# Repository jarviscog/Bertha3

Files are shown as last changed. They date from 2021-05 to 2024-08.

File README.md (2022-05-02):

# Bertha3

Bertha3 is a design of a split-flap display.

## Parts

Parts designed in Solidworks, and printed using the Ender3

## Parts used

[Stepper motor](https://www.adafruit.com/product/858)

## Code structure

The split flap is made up of a 2D array of split flaps called ```Bits```. The ```BitArray``` class controls all of the bits from 
one place. This is where you would print anything to the screen, or do any animations.
Create a new ```BitArray``` object, and call the functions inside to change what is displayed on the screen.

```display_layered_strings()``` is the highest level function for printing to the screen, printing an array of strings in any formatting you would like (see the docstring for more info)

Many different functions have been created to make writing to the screen as easy as possible.

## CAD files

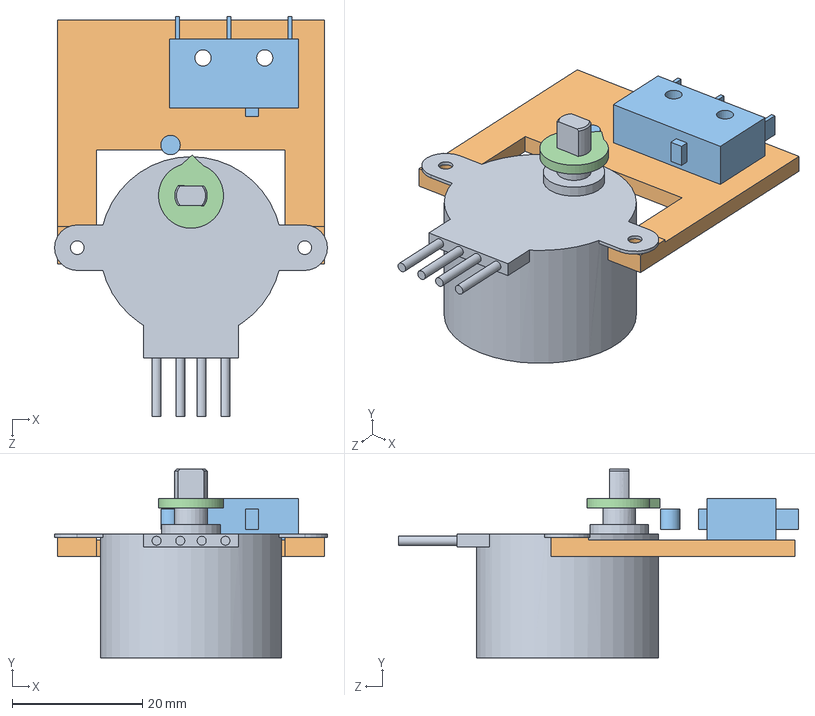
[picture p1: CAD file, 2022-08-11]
CAD Files/assemblies/position_encoder.SLDASM
42.0 x 29.0 x 61.6 mm
Motor
encoder_bracket
microswitch
rotating_thing_encoder

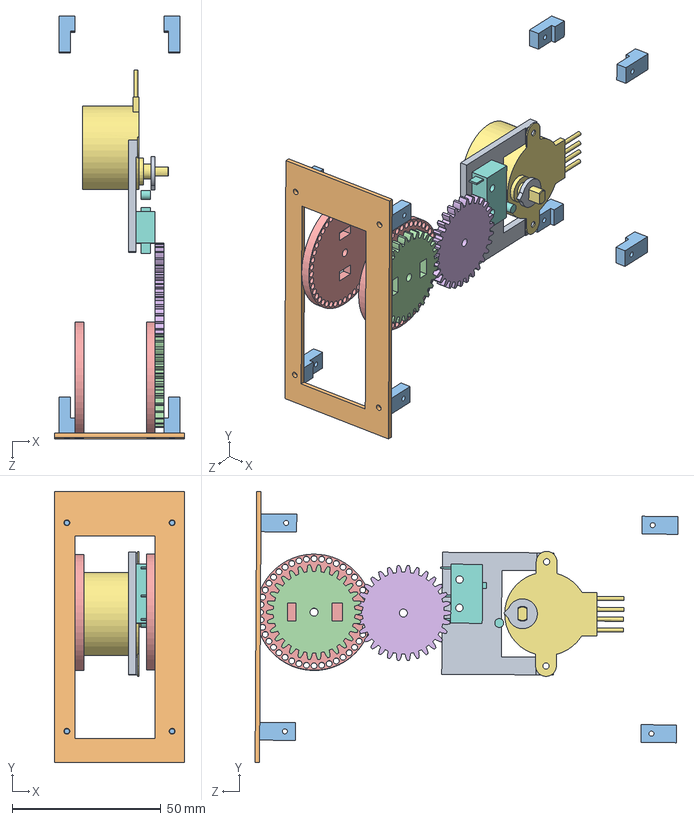
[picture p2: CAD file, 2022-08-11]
CAD Files/assemblies/mybit.SLDASM
43.7 x 91.0 x 142.0 mm
frontv2
fasteners x 8
barrel_gear
BarrelSide x 2
gear2
Motor
encoder_bracket
microswitch
rotating_thing_encoder

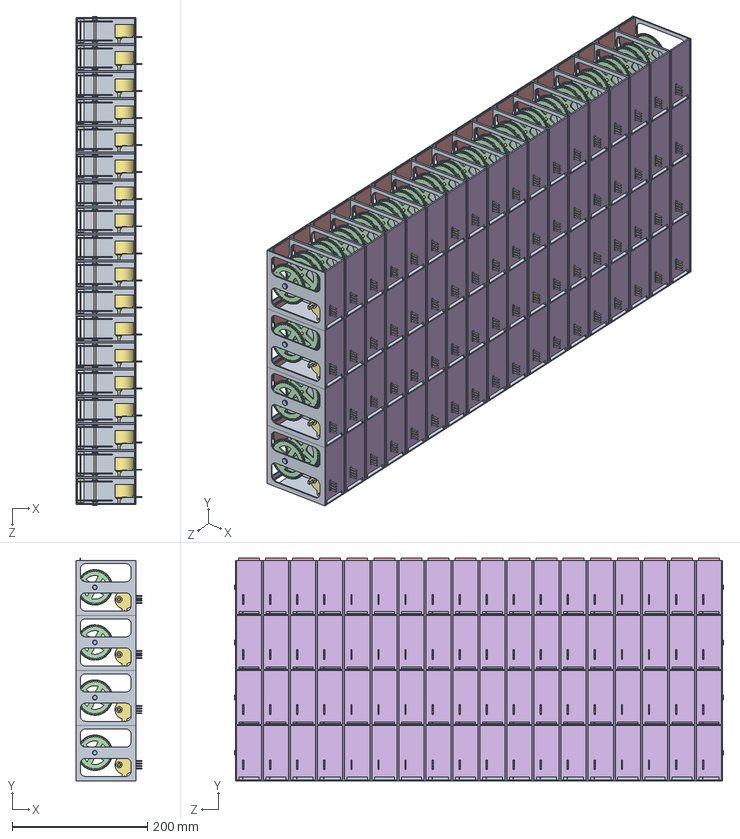
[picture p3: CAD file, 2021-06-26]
Parts/Screen.SLDASM
97.8 x 329.0 x 723.0 mm
Metal Rod x 72
EndCap x 144
SinisterGear x 144
Flap x 72
RearBox x 72
Motor x 72

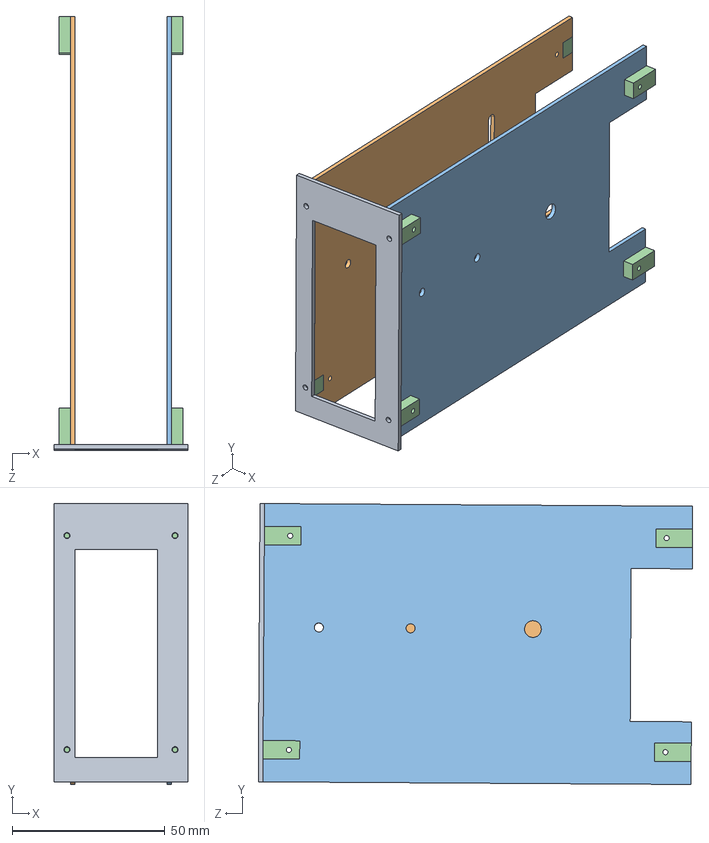
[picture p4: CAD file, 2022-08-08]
CAD Files/assemblies/mybit_frame.SLDASM
43.7 x 91.9 x 142.1 mm
Left
Right
frontv2
fasteners x 8

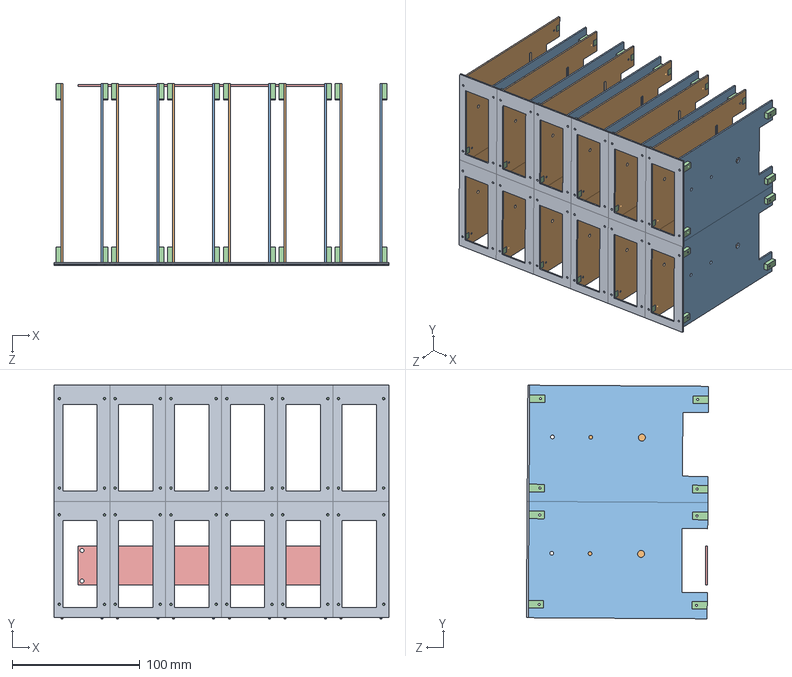
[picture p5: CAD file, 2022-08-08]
CAD Files/assemblies/simple_bit_assembly.SLDASM
262.2 x 182.9 x 142.6 mm
Left x 12
Right x 12
frontv2 x 12
fasteners x 96
motor_driver_pcb

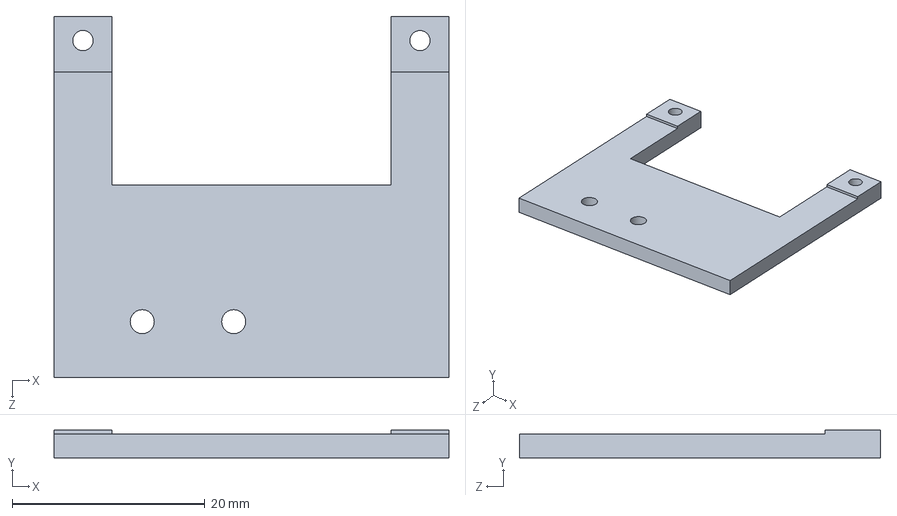
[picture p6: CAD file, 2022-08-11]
CAD Files/parts/encoder_bracket.SLDPRT
41.0 x 2.90 x 37.5 mm

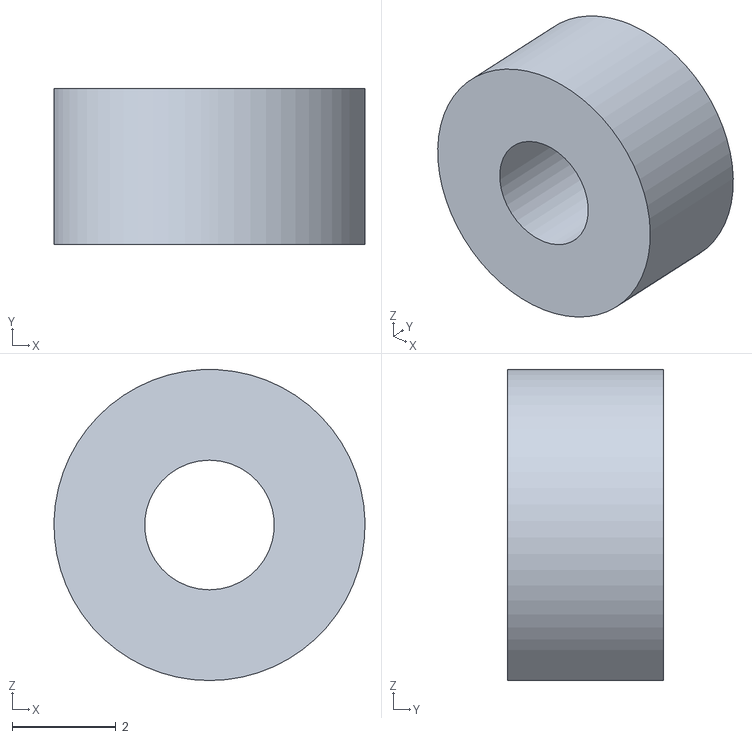
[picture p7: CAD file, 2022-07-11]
CAD Files/STL Files/spacer.STL
6.00 x 3.00 x 6.00

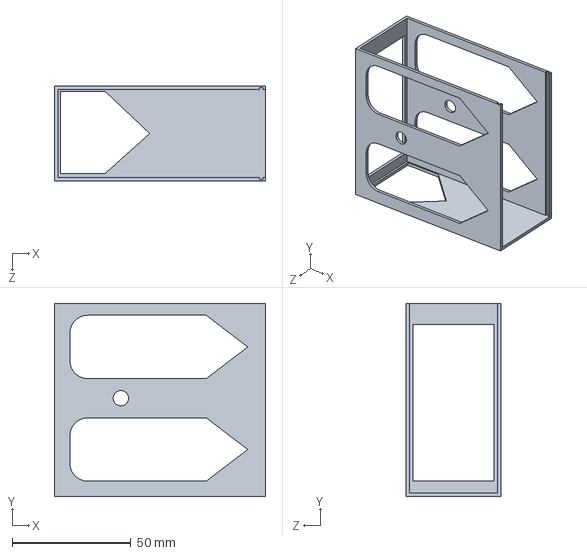
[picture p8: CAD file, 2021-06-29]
Parts/Box.SLDPRT
89.0 x 81.5 x 40.0 mm

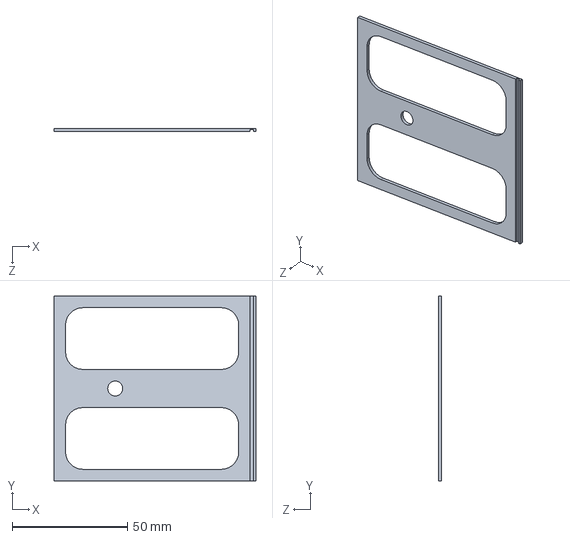
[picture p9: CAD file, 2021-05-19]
Parts/Box/LeftSideBox.SLDPRT
87.5 x 80.0 x 1.50 mm

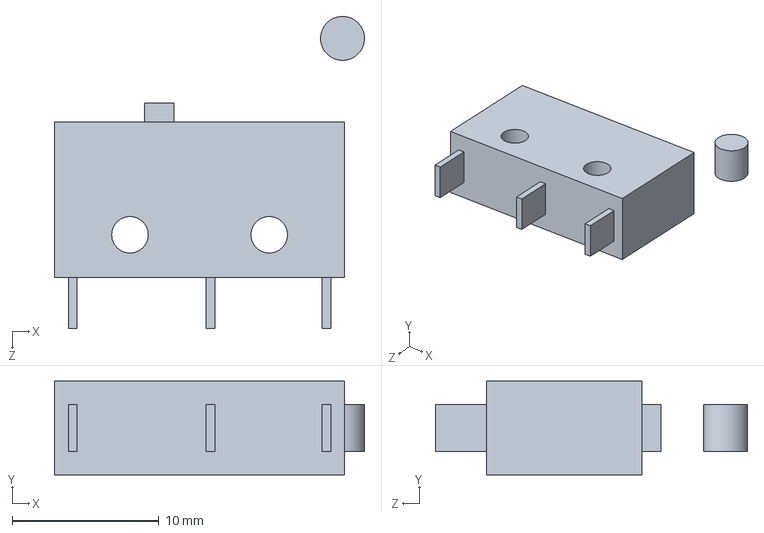
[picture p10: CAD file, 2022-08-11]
CAD Files/parts/microswitch.SLDPRT
21.1 x 6.40 x 21.3 mm

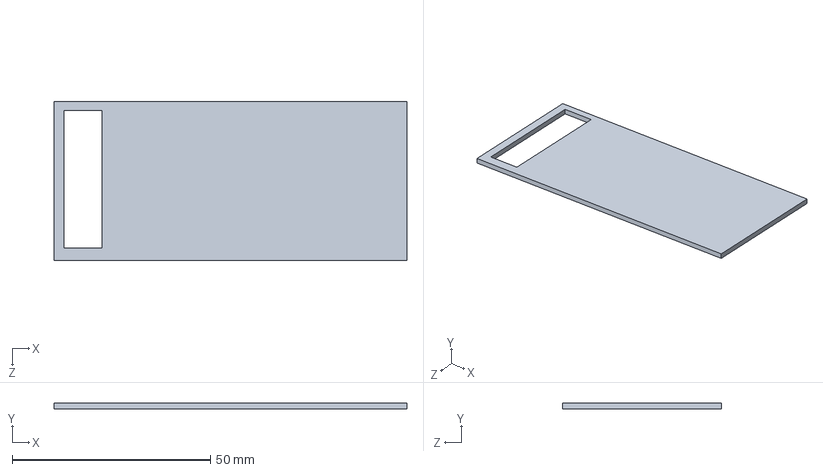
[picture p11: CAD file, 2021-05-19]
Parts/Box/BottomBox.SLDPRT
89.0 x 1.50 x 40.0 mm

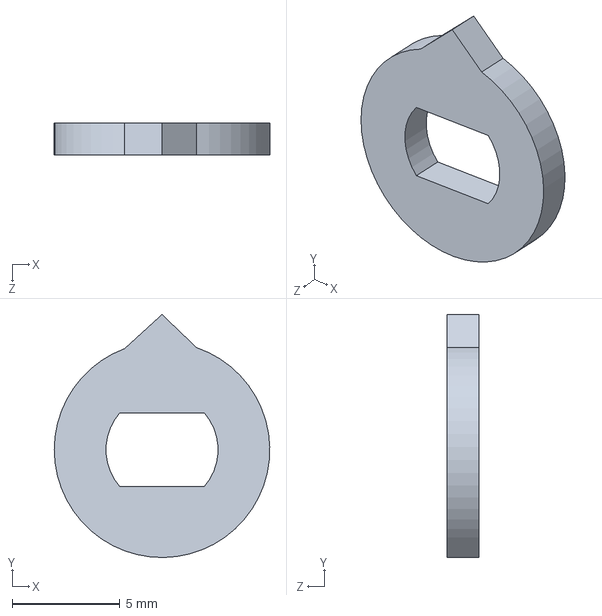
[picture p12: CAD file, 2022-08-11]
CAD Files/parts/rotating_thing_encoder.SLDPRT
10.00 x 11.3 x 1.50 mm

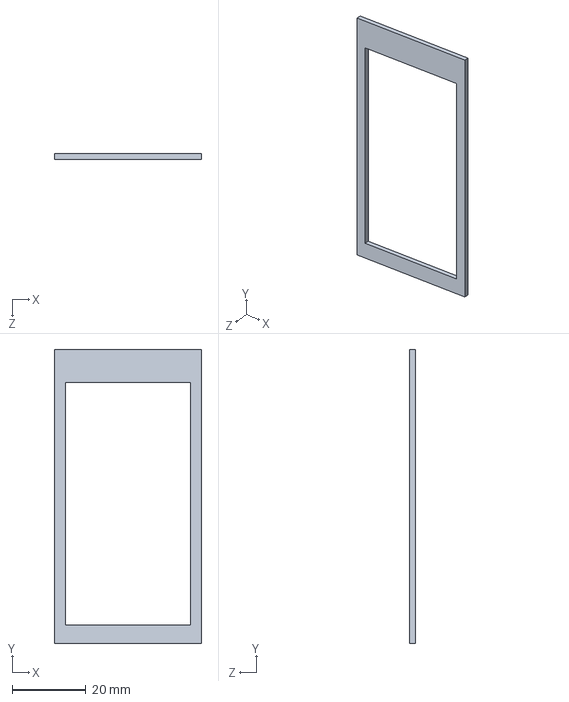
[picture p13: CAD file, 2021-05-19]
Parts/Box/FrontBox.SLDPRT
40.0 x 80.0 x 1.50 mm

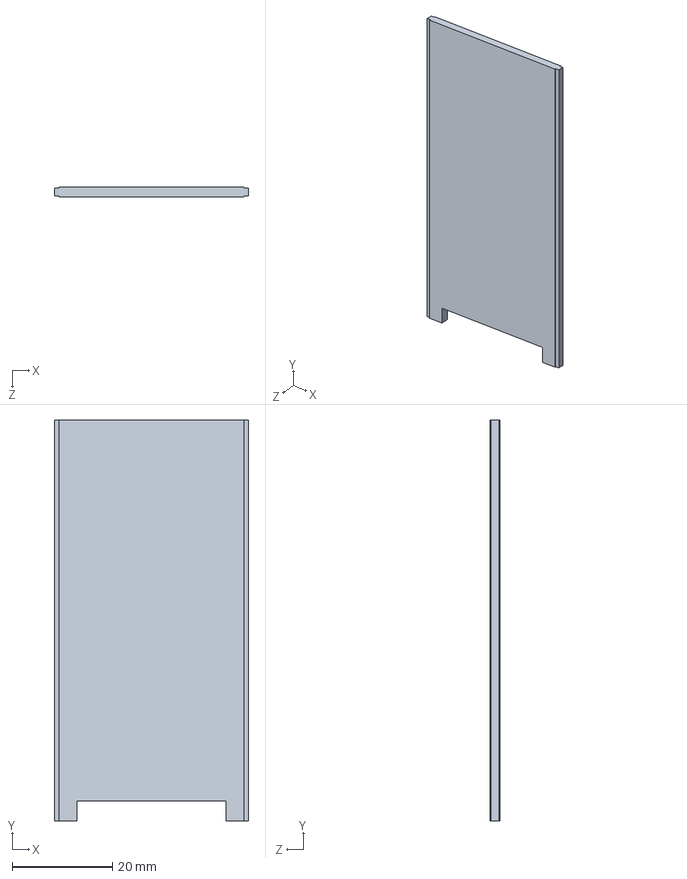
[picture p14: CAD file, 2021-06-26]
Parts/RearBox.SLDPRT
38.8 x 80.0 x 2.00 mm

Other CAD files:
CAD Files/parts/frontv2.SLDPRT
Parts/EndCap.SLDPRT
CAD Files/parts/fasteners.SLDPRT
Parts/SinisterGear.SLDPRT
CAD Files/STL Files/InnerBarrelStandoff.STL
CAD Files/STL Files/encoder_bracket.STL
CAD Files/STL Files/motor_standoff.STL
CAD Files/STL Files/rotating_thing_encoder.STL
CAD Files/drawings/Laser.SLDDRW
CAD Files/drawings/for_laser_cutting.SLDDRW
CAD Files/drawings/multipart2.SLDDRW
CAD Files/drawings/some_more_laser_cutting.SLDDRW
CAD Files/parts/Axel.SLDPRT
CAD Files/parts/BarrelSide.SLDPRT
CAD Files/parts/HallSensor.SLDPRT
CAD Files/parts/HallSensorStandoff.SLDPRT
CAD Files/parts/InnerBarrelStandoff.SLDPRT
CAD Files/parts/Left.SLDPRT
CAD Files/parts/Motor.SLDPRT
CAD Files/parts/Right.SLDPRT
CAD Files/parts/Standoff.SLDPRT
CAD Files/parts/backplate.SLDPRT
CAD Files/parts/barrel_gear.SLDPRT
CAD Files/parts/driving_gear.SLDPRT
CAD Files/parts/flapv2.SLDPRT
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

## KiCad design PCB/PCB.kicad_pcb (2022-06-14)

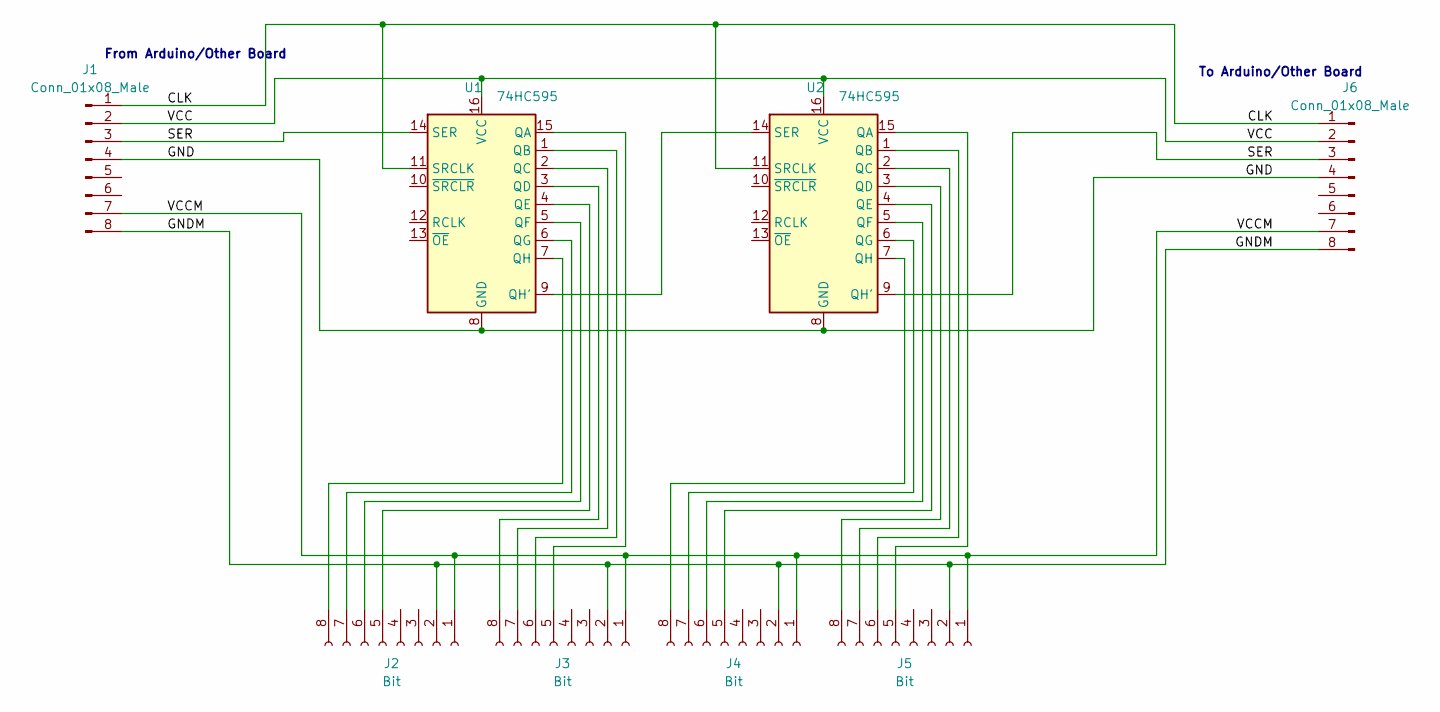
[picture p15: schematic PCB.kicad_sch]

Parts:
J1, J6: Conn_01x08_Male; JST_EH_B8B-EH-A_1x08_P2.50mm_Vertical
J2, J3, J4, J5: Bit; JST_EH_B8B-EH-A_1x08_P2.50mm_Vertical
U1, U2: 74HC595; DIP-16_W7.62mm_SMDSocket_SmallPads

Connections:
/CLK: J1.1, J6.1, U1.11 (SRCLK), U2.11 (SRCLK)
/GND: J1.4, J6.4, U1.8 (GND), U2.8 (GND)
/GNDM: J1.8, J2.2, J3.2, J4.2, J5.2, J6.8
/SER: J1.3, J6.3, U1.14 (SER), U2.9 (QH')
/VCC: J1.2, J6.2, U1.16 (VCC), U2.16 (VCC)
/VCCM: J1.7, J2.1, J3.1, J4.1, J5.1, J6.7
unnamed: J2.5, U1.4 (QE)
unnamed: J2.6, U1.5 (QF)
unnamed: J2.7, U1.6 (QG)
unnamed: J2.8, U1.7 (QH)
unnamed: J3.5, U1.15 (QA)
unnamed: J3.6, U1.1 (QB)
unnamed: J3.7, U1.2 (QC)
unnamed: J3.8, U1.3 (QD)
unnamed: J4.5, U2.4 (QE)
unnamed: J4.6, U2.5 (QF)
unnamed: J4.7, U2.6 (QG)
unnamed: J4.8, U2.7 (QH)
unnamed: J5.5, U2.15 (QA)
unnamed: J5.6, U2.1 (QB)
unnamed: J5.7, U2.2 (QC)
unnamed: J5.8, U2.3 (QD)
unnamed: U1.9 (QH'), U2.14 (SER)

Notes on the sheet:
From Arduino/Other Board
To Arduino/Other Board

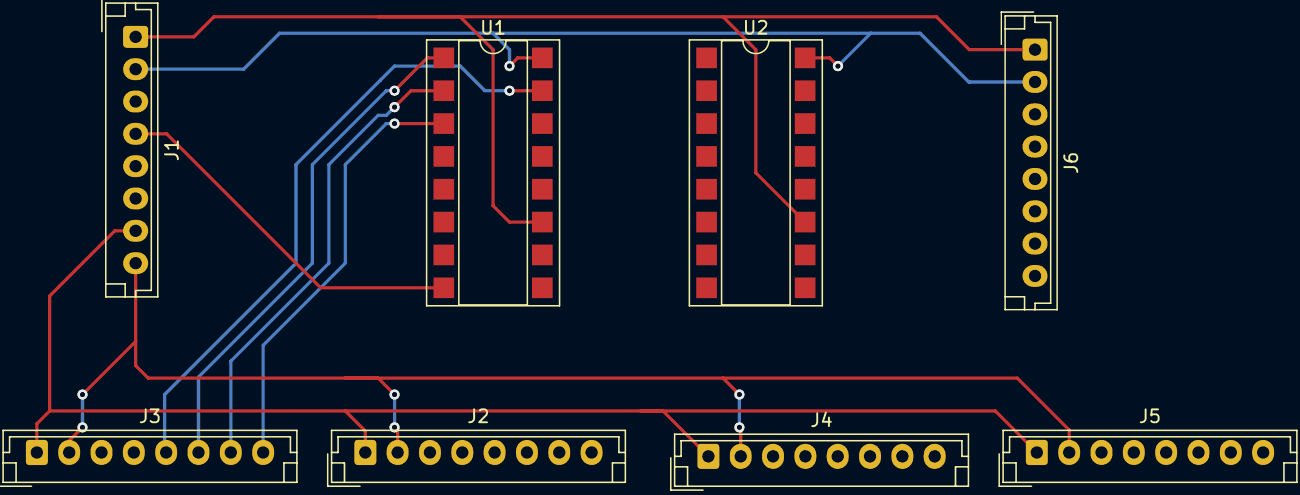
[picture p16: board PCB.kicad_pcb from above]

Board: 2 copper layers, 8 parts (0 on the bottom side), 23 nets.

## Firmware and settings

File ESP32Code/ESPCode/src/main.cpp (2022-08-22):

// /*
//   WiFiAccessPoint.ino creates a WiFi access point and provides a web server on it.

//   Steps:
//   1. Connect to the access point "yourAp"
//   2. Point your web browser to http://192.168.4.1/H to turn the LED on or http://192.168.4.1/L to turn it off
//     OR
//     Run raw TCP "GET /H" and "GET /L" on PuTTY terminal with 192.168.4.1 as IP address and 80 as port

//   Created for arduino-esp32 on 04 July, 2018
//   by Elochukwu Ifediora (fedy0)
// */


// #include <WiFi.h>
// #include <WiFiClient.h>
// #include <WiFiAP.h>

// // Control the builtin led
// #include "Freenove_WS2812_Lib_for_ESP32.h"
// #define LEDS_COUNT  8
// #define LEDS_PIN	48
// #define CHANNEL		0
// Freenove_ESP32_WS2812 rgb_led = Freenove_ESP32_WS2812(LEDS_COUNT, LEDS_PIN, CHANNEL, TYPE_GRB);
// byte m_color[5][3] = { {255, 0, 0}, {0, 255, 0}, {0, 0, 255}, {255, 255, 255}, {0, 0, 0} };

// byte RED[3] = {255,0,0};
// byte GREEN[3] = {0,255,0};
// byte BLUE[3] = {0,0,255};


// // WIFI Cridentials
// const char *ssid = "AeroBoard";
// const char *password = "esp32";

// WiFiServer server(80);

// void set_led(byte color[3]){

//     for (int i = 0; i < LEDS_COUNT; i++) {
// 			rgb_led.setLedColorData(i, color[0], color[1], color[2]);
// 			rgb_led.show();
// 			// delay(2);
// 	}


// }



// void setup() {

//     // Setup LED for debugging
//     rgb_led.begin();
//     rgb_led.setBrightness(100);

//     Serial.begin(115200);
//     Serial.println();
//     Serial.println("Configuring access point...");

//     // You can remove the password parameter if you want the AP to be open.
//     WiFi.softAP(ssid, password);
//     IPAddress myIP = WiFi.softAPIP();
//     Serial.print("AP IP address: ");
//     Serial.println(myIP);
//     server.begin();

//     Serial.println("Server started");
// }

// void loop() {
    
    
//     set_led(RED);
//     // Serial.println("Set color");


//     WiFiClient client = server.available();   // listen for incoming clients
//     if (client) {                             // if you get a client,
//     Serial.println("New Client connected");           // print a message out the serial port
//     String currentLine = "";                // make a String to hold incoming data from the client
//     while (client.connected()) {            // loop while the clWient's connected
//         // set_led(BLUE);
//         if (client.available()) {             // if there's bytes to read from the client,
//         char c = client.read();             // read a byte, then
//         Serial.write(c);                    // print it out the serial monitor
//         if (c == '\n') {                    // if the byte is a newline character

//             // if the current line is blank, you got two newline characters in a row.
//             // that's the end of the client HTTP request, so send a response:
//             if (currentLine.length() == 0) {
//             // HTTP headers always start with a response code (e.g. HTTP/1.1 200 OK)
//             // and a content-type so the client knows what's coming, then a blank line:
//             // client.println("HTTP/1.1 200 OK");
//             // client.println("Content-type:text/html");
//             // client.println();

//             // // the content of the HTTP response follows the header:
//             // client.print("Click <a href=\"/H\">here</a> to turn ON the LED.<br>");
//             // client.print("Click <a href=\"/L\">here</a> to turn OFF the LED.<br>");

//             // The HTTP response ends with another blank line:
//             client.println();
//             // break out of the while loop:
//             break;
//             } else {    // if you got a newline, then clear currentLine:
//             currentLine = "";
//             }
//         } else if (c != '\r') {  // if you got anything else but a carriage return character,
//             currentLine += c;      // add it to the end of the currentLine
//         }

        
//         // Serial.println("The client sent something:");
//         // Serial.println(currentLine);
//         // Serial.println("---------");
//         set_led(GREEN);
        
//         if (currentLine.endsWith("GET /Hello")) {

//           Serial.println("GOT SOME CODE!");

//         }

//       }
//     }
//     // close the connection:
//     set_led(RED);
//     client.stop();
//     Serial.println("Client Disconnected.");
//   }

// }
          

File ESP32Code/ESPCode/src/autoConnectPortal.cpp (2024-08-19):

#include "WiFiConnect.h" 

#include <WiFiClient.h>                      
#ifdef ARDUINO_ARCH_ESP8266  
#include <ESP8266HTTPClient.h>
#else  
#include <HTTPClient.h>
#endif

WiFiConnect wc;

// For internet connection
WiFiClient client;
HTTPClient http;
 
void configModeCallback(WiFiConnect *mWiFiConnect) {
  Serial.println("Entering Access Point");
}


void startWiFi(boolean showParams = false) {
 
  wc.setDebug(true);
  
  /* Set our callbacks */
  wc.setAPCallback(configModeCallback);

  //wc.resetSettings(); //helper to remove the stored wifi connection, comment out after first upload and re upload

    /*
       AP_NONE = Continue executing code
       AP_LOOP = Trap in a continuous loop - Device is useless
       AP_RESET = Restart the chip
       AP_WAIT  = Trap in a continuous loop with captive portal until we have a working WiFi connection
    */
    if (!wc.autoConnect("Aeroboard")) { // try to connect to wifi
      /* We could also use button etc. to trigger the portal on demand within main loop */
      wc.startConfigurationPortal(AP_WAIT);//if not connected show the configuration portal
    }
}


void setup() {
  Serial.begin(115200);
  while (!Serial) {
    delay(100);
  }
  Serial.println("....");
  delay (5000);
  startWiFi();

}

void loop() {
    delay(100);
    Serial.println("Testing with connection to internet...");

    http.begin(client, "http://ftp.mirrorservice.org/sites/archive.ubuntu.com/ubuntu/");

    int httpCode = http.GET();
    
    if (httpCode > 0) 
    {    
      
      // HTTP header has been send and Server response header has been handled
      Serial.printf("[HTTP] GET... code: %d\n", httpCode);
      
      // file found at server
      if (httpCode == HTTP_CODE_OK) 
      {
          Serial.println("HTTP_CODE_OK");
      }
      
    } else {
       Serial.printf("[HTTP] GET... failed, error: %s\n", http.errorToString(httpCode).c_str());
    }
    
    http.end();  
  
    // Wifi Dies? Start Portal Again
    if (WiFi.status() != WL_CONNECTED) {
      if (!wc.autoConnect()) wc.startConfigurationPortal(AP_WAIT);
    }
  
  delay (20000);
}

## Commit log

2021-03-28 Added all parts from Parts
    [BitAssembly.SLDASM, BottomBox.SLDPRT, Flap.SLDPRT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]
2021-03-28 Created STL file
    [Flap.STL, SinisterGear.STL]
2021-03-28 Removed Strange files
    [BitAssembly.SLDASM]
2021-04-02 Added More Parts
    [BitAssembly.SLDASM, Flap.SLDPRT, LeftSideBox.SLDPRT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]
2021-04-02 Added STL Files for other parts
    [BitAssembly - BottomBox-1.STL, BitAssembly - Flap-51.STL, BitAssembly - FrontBox-1.STL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]
2021-04-05 Extended box
    [BitAssembly.SLDASM, LeftSideBox.SLDPRT, RearBox.SLDPRT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]
2021-04-24 Added end cap
    [BitAssembly.SLDASM, BottomBox.SLDPRT, EndCap.SLDPRT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]
2021-04-24 Finished rod end
    [BitAssembly.SLDASM, EndCap.SLDPRT, Flap.SLDPRT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]
2021-04-25 Updated STL files
    [BitAssembly - BottomBox-1.STL, BitAssembly - EndCap-1.STL, BitAssembly - Flap-51.STL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]
2021-04-25 Fixed stl files for print
    [BitAssembly - BottomBox-1.STL, BitAssembly - EndCap-1.STL, BitAssembly - EndCap-2.STL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]
2021-04-25 Small Changes
    [BitAssembly.SLDASM, rightSideBox.SLDPRT]
2021-05-02 Fixed issues in 3d print
    Changed Stl files
    [BitAssembly - BottomBox-1.STL, BitAssembly - EndCap-1.STL, BitAssembly - EndCap-2.STL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]
2021-05-19 Fixed tight fitting parts
    [BitAssembly.SLDASM, BottomBox.SLDPRT, EndCap.SLDPRT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]
2021-06-25 New part organization structure pt 1
    [Bit.SLDASM, BitAssembly.SLDASM, Box.SLDPRT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]
2021-06-26 New part organization structure pt 2
    [Bit - Box-1.STL, Bit - EndCap-1.STL, Bit - EndCap-2.STL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]
2021-06-26 Added bit stl file demo
    [Bit.STL]
2021-06-26 Added more demo files
    [Screen.SLDASM]
2021-06-29 Made Parts printable
    [Bit.SLDASM, Box.SLDPRT, Box.STL]
2022-04-25 Finished function to print strings to the screen
2022-05-02 Finished print stacked strings
2022-06-14 Updated new bit, and started working on summer version:)
    [Axel.SLDPRT, Back.SLDPRT, Barrel.SLDASM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]
2022-07-11 cleaned up and added new solidworks files
    [Assem1.SLDASM, Axel.SLDPRT, Back.SLDPRT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]
2022-08-08 modified main hole in model
    flaps should now freely fall through the hole and not get stuck on the bottom portion of the front piece.
    [BarrelSide.SLDPRT, back.SLDPRT, frontv2.SLDPRT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]
2022-08-08 made some changes to support a casing for multiple bits
    Created a backplate to hold multiple bits. Also made the material thickness in the models thinner (3mm to 1.5mm)
    [Left.SLDPRT, Right.SLDPRT, fasteners.SLDPRT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]
2022-08-08 deleted some old files
    [Assem1.SLDASM, Flap.SLDPRT, Front.SLDPRT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]
2022-08-08 next iteration of aeroboard model
    [Bit.SLDASM, Display.SLDASM, FlapPrinting.SLDASM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]
2022-08-11 made some models for a new iteration of a position encoder
    [encoder_bracket.SLDPRT, encoder_bracket.STL, microswitch.SLDPRT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]
2022-08-22 Added ESP32 Code
